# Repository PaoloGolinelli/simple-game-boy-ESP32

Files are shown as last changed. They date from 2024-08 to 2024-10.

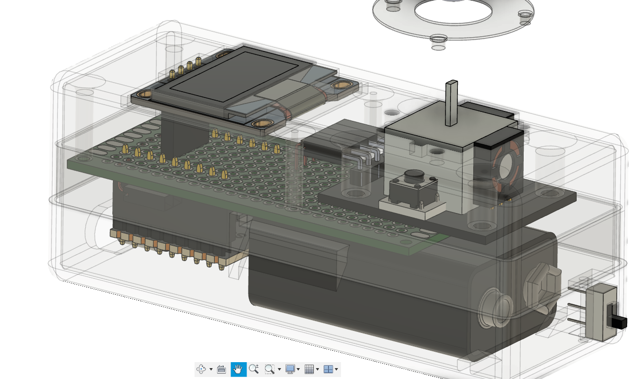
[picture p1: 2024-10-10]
circuit S3 mini/component_assembly_top_view.png

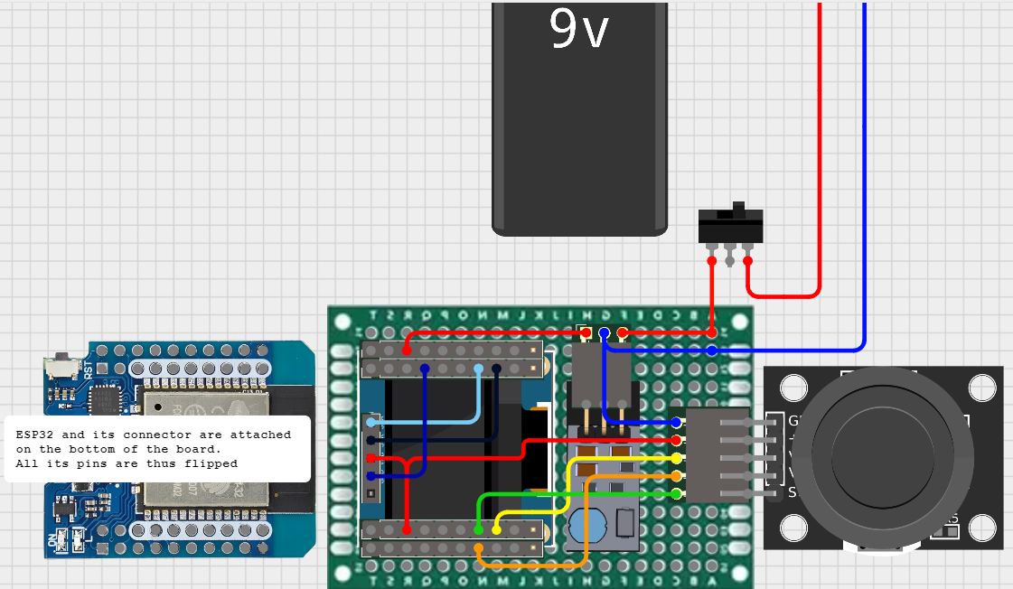
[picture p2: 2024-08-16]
circuit WROOM D1 mini/circuit_on_perfboard_schematic.png

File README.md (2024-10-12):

# simple-game-boy-ESP32
In this repository you can find all the material required to build a DIY console using the micro controller ESP32

## Content of the repository
- code for ESP32:
    In the beginning of the code you can select 3 preprocessor's variables which are used to differentiate between the boards you're using. 
    - MULTIPLAY: set to true to add the multiplayer games; require Bluethooth (BT) communication. Use this only if you plan on building two consoles to play with friends.
    - BT_CLASSIC: set to true if you want to use the classic BT protocol; set to false to use the BT Low Energy (BLE) protocol. If possible I recommend using the classic protocol, because it is faster and more resilient, but consumes more energy. ESP32 S3 mini has only BLE integrated, while WROOM has both.
    - ESP32_MOD: set to true if you're using WROOM module, false if youre using S3 mini. Used only to define the pins.

- schematic diagram of the circuit on breadboard
    Before building the whole console try it on breadboard to verify your board and components are compatible with the code.
    - S3 mini zero: https://app.cirkitdesigner.com/project/c8f486d2-5efd-4bba-b75a-e2c31b4107fe
    - WROOM D1 mini: https://app.cirkitdesigner.com/project/0857a7c8-4681-452b-a24f-5374fa44a8b1

- schematic diagram of the circuit to weld on matrix perforated board ("PCB")
    The 3D files to print the casing are specific to the S3 mini zero version. Even tho I provide the sketches to implement on perf-board with both micro-controllers, only the first is complete of all components.
    - S3 mini zero: https://app.cirkitdesigner.com/project/2bdec6b9-4f45-4acb-8dcb-3ecd578236df
        For the positioning of the components on the perfboard please refer to the 3D model of the assembly. Mind that some components are welded on the front, while others are on the back.
    - WROOM D1 mini: https://app.cirkitdesigner.com/project/fdfa9b3a-22b1-4d85-bbf5-8aa331098814

- stl file for 3D printing the case and positioning of the components
    - game_boy_assembly
    - top_cover
    - bottom_cover
    - joystick_head
    - joystick_lid
    - assembly_3Dprint_gcode_cura: CURA project with assembly, although you may configure it to your 3D printer settings

## Components required to make your own
- ESP32 S3 MINI Zero (or WROOM D1 mini)
- 2 axis joystick: KY-023
- LCD display: SSD1306 OLED 0.96'' I2C IIC 128x64
- breadboard
- jumper M/M
- jumper M/F
- matrix board 7x3
- slide switch: SS-12D00G 4mm
- 9V battery clip connector
- 9V battery
- step down voltage regulator: DD4012SA 5V

### Building Instructions 

## Required tools
- filament 3D printer
- welder

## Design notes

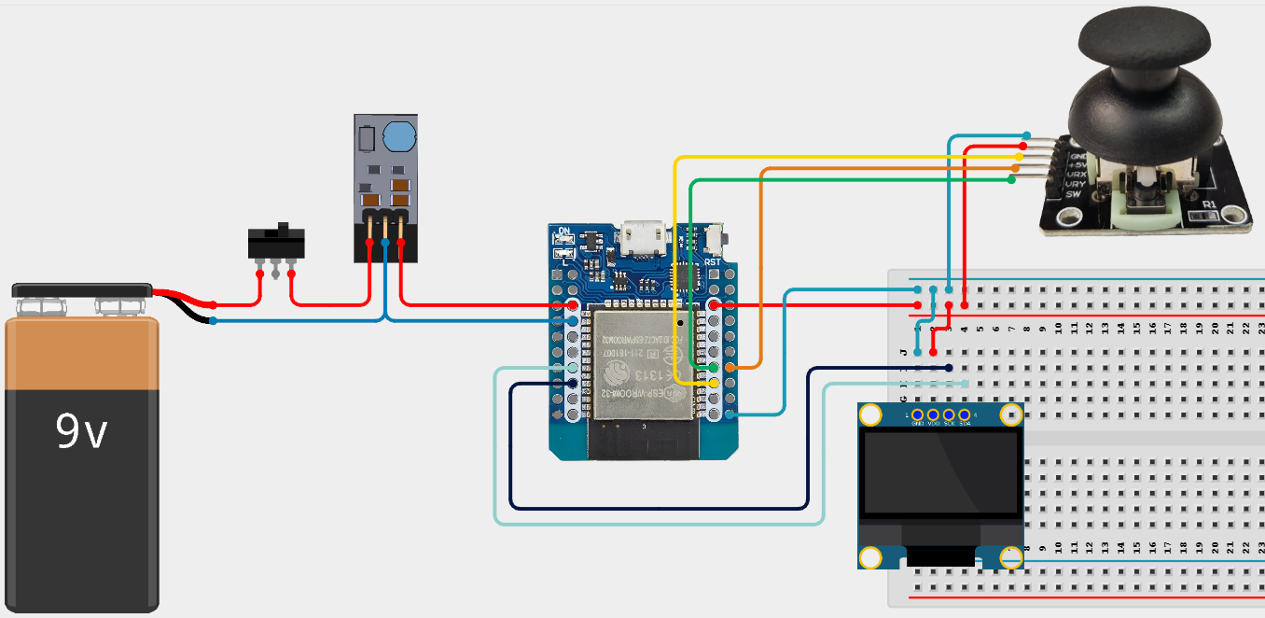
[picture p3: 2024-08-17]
circuit WROOM D1 mini/circuit_on_breadboard_schematic.png

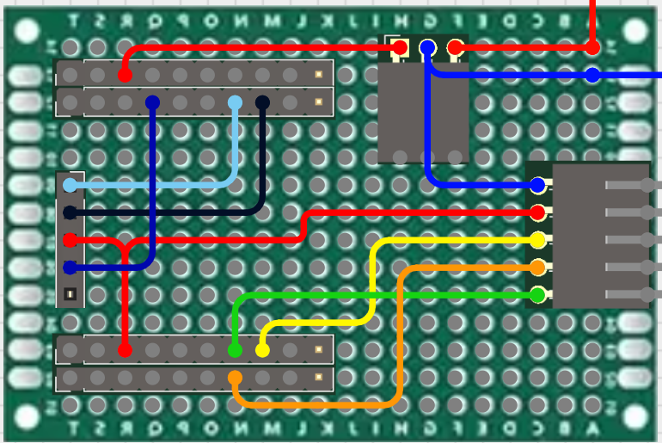
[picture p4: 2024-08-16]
circuit WROOM D1 mini/perfboard_circuit.png

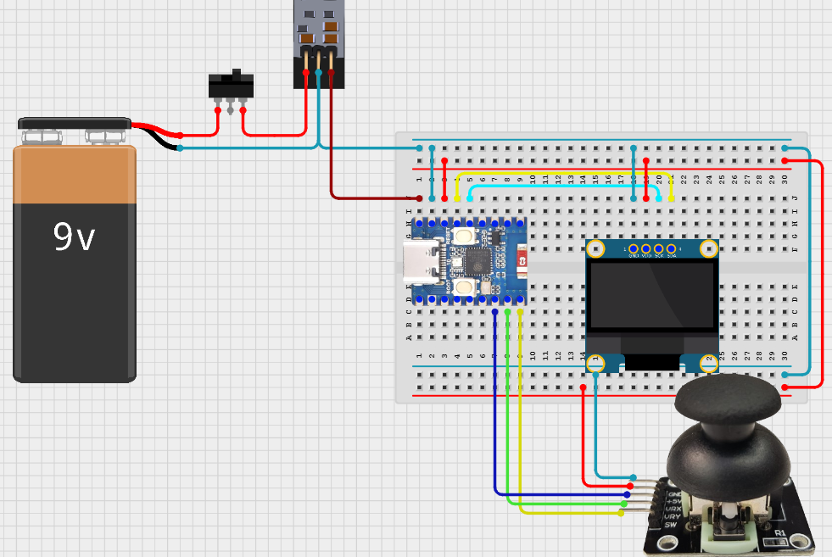
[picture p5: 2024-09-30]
circuit S3 mini/circuit_on_breadboard.png

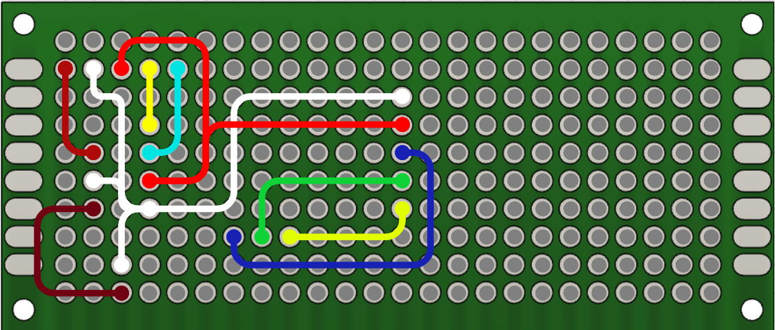
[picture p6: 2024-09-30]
circuit S3 mini/perfboard_circuit.png

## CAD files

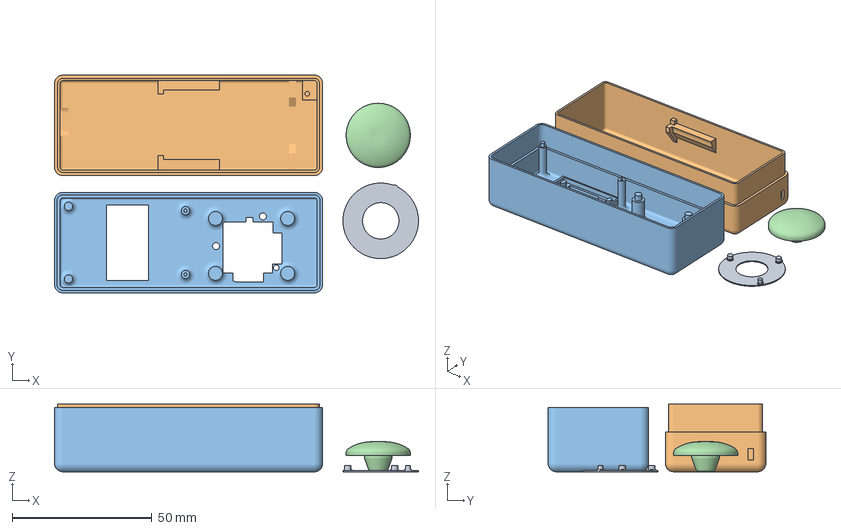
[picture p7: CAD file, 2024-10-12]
case 3D files/assembly_3Dprint_gcode_cura.3mf
130.3 x 78.0 x 24.2 mm
joystick_lid.stl
bottom_cover.stl
top_cover.stl
joy_head.stl

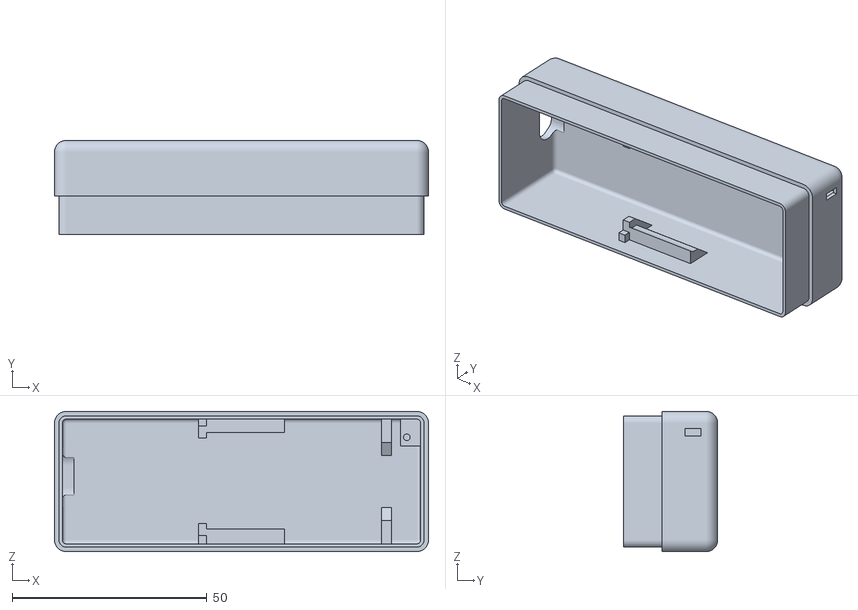
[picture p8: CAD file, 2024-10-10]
case 3D files/bottom_cover.stl
96.0 x 24.2 x 36.0

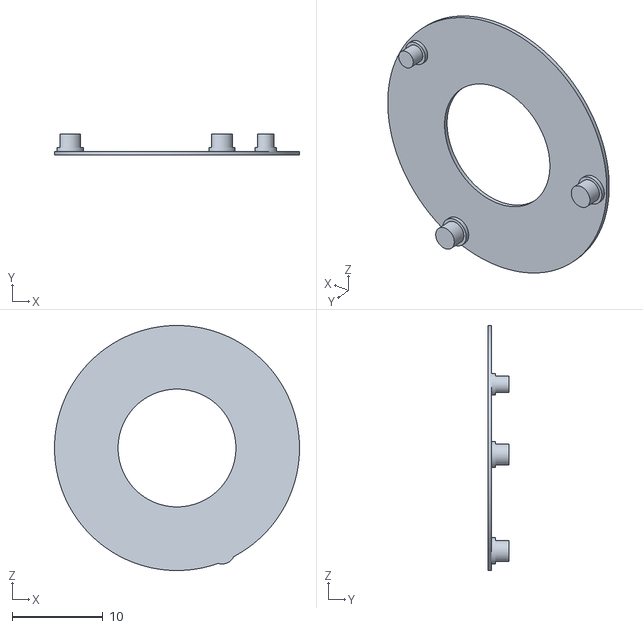
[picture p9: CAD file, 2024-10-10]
case 3D files/joystick_lid.stl
27.0 x 2.30 x 27.0

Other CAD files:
case 3D files/game_boy_assembly_fusion.f3z

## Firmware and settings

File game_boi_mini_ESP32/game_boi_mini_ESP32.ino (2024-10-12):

// -------------------------------------------------------------------------------------------------------
#define   MULTIPLAY       true    // set to true to allow for multiplayer games, otherwise set to false
#define   BT_CLASSIC      false   // set to true to use BT classic, false to use Bluetooth Low Energy 
#define   ESP32_MOD       false   // set to true if you want to use a ESP32 wroom, false to use a s3 mini 
// -------------------------------------------------------------------------------------------------------

#include <SPI.h>
#include <Wire.h>
#include <Adafruit_GFX.h>
#include <Adafruit_SSD1306.h>
#include <cmath>
#include <String.h>

#if (MULTIPLAY) // ------------------------- MULTIPLAYER
  #if (BT_CLASSIC)
    #include "BluetoothSerial.h"
    #include "esp_bt_device.h"
    #include <esp_mac.h>
  #else
    #include <BLEDevice.h>
    #include <BLEServer.h>
  #endif
#endif // ----------------------------------------------

// Macro functions
#define SIGN(x) ((x) > 0 ? 1 : ((x) < 0 ? -1 : 0))
#define ROUND_TO_1_DECIMALS(x) (int(x*10.0) / 10.0)


// Game parameters
#define   SCREEN_WIDTH    128   // OLED display width, in pixels
#define   SCREEN_HEIGHT   64    // OLED display height, in pixels
#define   SNAKE_WIDTH     6     // Snake display width, in pixels
#define   SNAKE_HEIGHT    6     // Snake display height, in pixels
#define   POOL_FORCE_COEF 5.6   // Multiplier of force to calc pool initial velocity 
const int t_menu =        700;  // if pressed for this amount of ms returns to menu
const int t_sample_menu = 200;  // ms each sample is made in the menu selection
const int t_bounce =      40;   // time in ms to account for switch bouncing
#define   ANALOG_RES      4095  // Resolution of ADC
#define   d_to_r          3.14/180.0


// Declaration for an SSD1306 display connected to I2C (default pins are SDA: GPIO21, SCL: GPIO22)
#define          OLED_RESET    -1    // Reset pin # (or -1 if sharing Arduino reset pin)
Adafruit_SSD1306 display (SCREEN_WIDTH, SCREEN_HEIGHT, &Wire, OLED_RESET);

// define a struct to handle coordinates (double x,y, and direction)
struct crd {  // coordinate
  double x;
  double y;
  int    d;   // snakes heading direction for each coordinate
};

#if (MULTIPLAY) // ------------------------- MULTIPLAYER
  #define NRGAMES 5   // number of games
  const char *options[NRGAMES] = { 
    " Snake ", 
    " Pool ", 
    " Hit the target ",
    " Pong multiplayer ",
    " Calibration "};
#else // --------------------------------- SINGLE PLAYER
  #define NRGAMES 4   // number of games
  const char *options[NRGAMES] = { 
    " Snake ", 
    " Pool ", 
    " Hit the target ",
    " Calibration "};
#endif // ----------------------------------------------

const char *difficult[3] = {
  " Easy ",
  " Medium ",
  " Hard " };

#if (ESP32_MOD) // Input Pin Wroom
  const int     AI1           = 35;   // IO26 - analog signal x joystick
  const int     AI2           = 26;   // IO18 - analog signal y joystick
  const int     switchPin     = 19;   // IO19
  const int     SCLpin        = 22;   // IO21
  const int     SDApin        = 21;   // IO21
#else           // Input Pin S3 mini
  const int     AI1           = 8;    // GP8 - analog signal x joystick
  const int     AI2           = 9;    // GP9 - analog signal y joystick
  const int     switchPin     = 7;    // GP7
  const int     SCLpin        = 2;    // GP1
  const int     SDApin        = 1;    // GP2
#endif

// global variables
int           gameRate;               // time in ms between moves
unsigned long t, t_press, t_release;

// snake variables
bool  alive           = true;       
int   length;                   // current snake length
crd   position[200]   = {0};    // array containing snake's position
crd   food;
int   nr_width        = SCREEN_WIDTH/SNAKE_WIDTH;
int   nr_height       = SCREEN_HEIGHT/SNAKE_HEIGHT;

// pool variables
crd          balls[4];          // initial position to be set at beginning of game
crd          b_vel[4];          // define the carthesian velocity of the balls
crd          stick[3];          // defines the position of the stick
bool         bhole[4];          // true if they end up in a hole
double       stick_angle, stick_F;
const double hole_R   = 7;
const double ball_R   = 4;
const double stick_L  = 18;
const double dt       = 0.03;   // integration time in seconds
const double fr_coeff = 0.4;    // friction coefficient

// hit the target variables
int           d_range = 8;
double        dist, dist_tot;
unsigned long t_tot;
double        score;

#if (MULTIPLAY) // ----------- MULTIPLAYER -------------------------
  // BlueTooth variable
  #if (BT_CLASSIC)
    BluetoothSerial SerialBT; 
    uint8_t slaveMACAddress[6] = {0x32, 0xAE, 0xA4, 0x07, 0x0D, 0x66}; // slave MAC address
    uint8_t oldMACAddress[6];
  #else
    #define SERVICE_UUID        "37859a32-9f35-4408-b4e8-ad61f9bc1f31"
    #define CHARACTERISTIC_UUID "e21f0560-f548-4c6c-a189-81b2264e5485"

    //static BLEUUID serviceUUID(SERVICE_UUID);
    //static BLEUUID charUUID(CHARACTERISTIC_UUID);
    static BLEUUID serviceUUID("37859a32-9f35-4408-b4e8-ad61f9bc1f31");     // DEBUG
    static BLEUUID charUUID("e21f0560-f548-4c6c-a189-81b2264e5485");

    // server
    BLEServer         *pServer          = NULL;
    BLECharacteristic *pCharacteristic  = NULL;
    bool    deviceConnected     = false;
    bool    oldDeviceConnected  = false;    
    // client
    static  BLERemoteCharacteristic *pRemoteCharacteristic;
    static  BLEAdvertisedDevice     *myDevice;
    static  boolean connected   = false;
    // common
    bool    notified;
    double  received_value;
  #endif

  // pong variables
  #define     XV        70      // ball's horizontal velocity
  #define     MAX_XV    110     // ball's max horizontal velocity
  double      max_t_v = 0.05;   // max pixels a tile can move per millisecond
  const int   tile_H  = 10;     // nr of pixels defining the tile height
  const int   tile_W  = 3;      // nr of pixels defining the tile width
  const int   bord_W  = 3;      // border width
  const int   v_bound = 10;     // pixel above field (for displaying score)
  const int   bR      = 2;      // ball radius
  crd         ball_xy;          // ball coordinates
  crd         ball_v;           // ball velocities
  double      t_y1, t_y2;       // y coordinates of the two tiles
  crd         pr_ball_xy;       // previous ball coordinates
  double      pr_y1, pr_y2;     // previous y coordinates of the two tiles
  double      Dt_y1;            // receiver tile difference with previous y coord
  bool        scored;           // turned to true when it needs to update the score
  bool        is_master;        // set to T when gaimboi is master in BT communication     
  bool        play_receive;     // set to T when the current device is receiving the ball
  int         score_1, score_2; // score of the two players

#endif // ----------------------------------------------------------


// joystick variables
double  xa = 238, xd = 4.30, xe = -10.89;  // parabola parameters
double  ya = 192, yd = 5.33, ye = -18.75;  // initial calibration
double  Xval, Yval, Xlin, Ylin, magn, theta;
int     dir, precDir;
bool    sw_press = true;

// menu variables
bool    gotomenu, mnpress, sw_rel;
int     selected = 0;
int     entered  = -1;

// Task handles for parallel programming
TaskHandle_t handle_snake_joy_read;

// functions
void starting_animation ();
void menu               ();                 // displays menu to choose the game
void readJoystick       ();                 // read joystick values
  void calculate_dir    ();                 // calculate direction indicated by joystick
  void calibrate        ();                 // calibration procedure defines parabola parameters to linearize joystick readings
void ICACHE_RAM_ATTR sw_activity (void);    // deals joystick switch pressing and releasing

void snake_game         (); 
  void move             (int);              // function moves snake accordingly to the direction
  void eat              (bool);             // if heading position equals food position it increment snakes length and place new food; bolean defines first call
  void printFrame       ();                 // print frame on display

void pool_game          ();
  void pool_aim         ();
  void pool_balls_anim  ();
  void pool_printfield  (bool = false, bool = false);
  void collision        (int, int);
  void hole_ball        (int);

void target_game        ();

#if (MULTIPLAY) // -------------- MULTIPLAYER GAMES ----------
void pong_game          ();
  bool initialize_BT    ();                 // starts BT in master/slave mode and pair the devices
#if (!BT_CLASSIC)
  bool connectToServer  ();                 // used by slave to connect to server
#endif
  void pong_printfield  ();                 // prints the two tiles, the ball and the score 
#endif // ----------------------------------------------------


void setup() {
  Serial.begin(115200);
  Serial.printf("\nInitiate adjustment\n");

  pinMode(switchPin, INPUT_PULLUP);

  Wire.begin(SDApin, SCLpin); // define the pins for I2C (SDA, SCL)

  attachInterrupt(digitalPinToInterrupt(switchPin), sw_activity, CHANGE);
  t_release = millis();
  t_press   = millis();

  // SSD1306_SWITCHCAPVCC = generate display voltage from 3.3V internally
  if(!display.begin(SSD1306_SWITCHCAPVCC, 0x3C)) { // Address 0x3D for 128x64
    Serial.println(F("SSD1306 allocation failed"));
    for(;;) delay(1); // Don't proceed, loop forever
  }

  // starting animation "GAIM BOY"
  starting_animation();

  delay(500);
  display.clearDisplay();

  display.setTextColor(1); display.setTextSize(1);
  display.setCursor(5, 20); display.print("At any moment press");
  display.setCursor(5, 29); display.print("the switch for ~1 s");
  display.setCursor(5, 38); display.print(" to return to menu");
  display.display();

  delay(100);

  // display "press button":
  while (sw_press)
    delay(1);

  // Milliseconds at which switch is pressed defines random seed
  randomSeed(millis()%1000);

  // menù here going through the games
  menu();
}


void loop() {

  if (gotomenu) {
    menu();
  }
  if (selected == 0) 
    snake_game();
  else if (selected == 1) {
    pool_game();
  }
  else if (selected == 2) {
    target_game();
  }
#if (MULTIPLAY) // ----------- MULTIPLAYER ---------
  else if (selected == 3) {
    pong_game();
  }
  else if (selected == 4) {
    calibrate();
  }
#else // -------------------- SINGLE PLAYER --------
  else if (selected == 3) {
    calibrate();
  }
#endif // ------------------------------------------

  delay(100);
}


void starting_animation() {
  double  tsnake = 120;
  double  angle;
  int     sign;
  crd     aimer;
  aimer.x = 160;
  aimer.y = 40;

  display.setTextColor(1);
  display.setTextSize(3);

  // balls initial position and velocities
  balls[0].x = 23;    balls[0].y = 41;
  b_vel[0].x = 0;     b_vel[0].y = 0;
  balls[1].x = -6;    balls[1].y = 36;
  b_vel[1].x = 35.5;  b_vel[1].y = 10;

  t_tot = millis();
  while (millis() - t_tot <= 3000) {
    display.clearDisplay();
    display.setCursor(28, 0);   display.println(F("GAIM"));
    display.setCursor(37, 43);  display.println(F("B I"));

    // calculate new aimer coords
    aimer.x = 64.0 + 2.0*pow(3.0-((millis()-t_tot)/1000.0), 2);
    aimer.y = 54.0 - 2.2*pow(3.0-((millis()-t_tot)/1000.0), 3);

    display.drawCircle(aimer.x, aimer.y, d_range, 1);
    display.drawCircle(aimer.x, aimer.y, 2, 1);
    display.drawFastHLine(aimer.x-(d_range+1), aimer.y, 2*(d_range+1)+1, 1);
    display.drawFastVLine(aimer.x, aimer.y-(d_range+1), 2*(d_range+1)+1, 1);

    for (int i = 0; i < 2; i++) {
      balls[i].x += b_vel[i].x * dt;
      balls[i].y += b_vel[i].y * dt;

      // dinamic rolling friction:
      angle = atan(b_vel[i].y/b_vel[i].x);
      sign = b_vel[i].x >= 0 ? 1 : -1;
  
      if (fabs(b_vel[i].x) > 0.11)
        b_vel[i].x -= sign*0.2*cos(angle);
      else
        b_vel[i].x = 0;   // static friction: too slow -> come to a stop

      if (fabs(b_vel[i].y) > 0.11)
        b_vel[i].y -= sign*0.2*sin(angle);
      else
        b_vel[i].y = 0;   // static friction 

      display.fillCircle(balls[i].x, balls[i].y, ball_R, 1);
    }

    if (sqrt(pow(balls[0].x - balls[1].x, 2) + pow(balls[0].y - balls[1].y, 2)) <= 2*ball_R)
      collision(0, 1);

    display.display();
  }

  int sn_d = 16; // snake dimension
  display.setTextColor(0);
  display.setTextSize(2);

  // snake's initial positions
  length = 6;
  for (int s = length-1; s >=0 ; s--) {
    position[s].x = -sn_d*s - sn_d/2; 
    position[s].y = SCREEN_HEIGHT/2+2;
  }

  for (int n = 0; n < 2*(length)+3; n++) {
    t = millis();
    display.display();

    for (int l = 0; l < length; l++)
      position[l].x += sn_d/2;

    display.fillRect(0, SCREEN_HEIGHT/2-10, SCREEN_WIDTH, 20, 0);

    // display snake's head
    display.fillRoundRect(position[0].x-sn_d/2-5, position[0].y-sn_d/2, sn_d+5, sn_d, sn_d/4+1, 1); // below mouth

    if (n < 2*length-4 || n >= 2*length-1)
      display.fillTriangle(position[0].x-3, position[0].y, position[0].x+sn_d/2, position[0].y+1, position[0].x+sn_d/2, position[0].y-1, 0); // mouth
    else
      display.fillTriangle(position[0].x-1, position[0].y, position[0].x+sn_d/2, position[0].y+5, position[0].x+sn_d/2, position[0].y-5, 0); // mouth

    for (int l = 1; l < length-1; l++)
      display.fillRect(position[l].x - sn_d/2, position[l].y - sn_d/2, sn_d, sn_d, 1);

    display.fillCircle(position[0].x-8, position[0].y-8, 4, 1);                                 // above eye
    display.fillCircle(position[0].x-8, position[0].y-8, 2, 0);                                 // eye

    // display tail
    display.fillRect(position[length-1].x-sn_d, position[length-1].y-sn_d/2, sn_d+8, sn_d, 1);

    display.fillCircle(position[length-1].x+3, position[length-1].y+sn_d/2+1, 7, 0);
    display.fillCircle(position[length-1].x-6, position[length-1].y-sn_d/2-1, 7, 0);
    display.fillTriangle(position[length-1].x-sn_d, position[length-1].y-sn_d/2, position[length-1].x-sn_d, position[length-1].y+sn_d/2, position[length-1].x-sn_d+9, position[length-1].y+sn_d/2, 0);

    display.fillCircle(balls[0].x, balls[0].y, ball_R, 1);  // display deleted ball
    display.fillCircle(balls[1].x, balls[1].y, ball_R, 1);  // display deleted ball

    display.setCursor(-65+n*sn_d/2, SCREEN_HEIGHT/2-5); display.print(F("MINI"));

    while (millis() - t < tsnake)
      delay(1);
  }
}


void menu () {
  gotomenu = false;
  selected = 0;
  
  while(!sw_press)
    delay(1);

  mnpress = false;
  while (true) {
    readJoystick();
    calculate_dir();

    if (dir == 1) {
      selected--;
    }
    else if (dir == 3) {
      selected++;
    }

    selected = (selected + NRGAMES) % NRGAMES;

    if (mnpress) {
      break;
    }
    else {
      display.clearDisplay();
      display.setTextSize(1);             
      display.setTextColor(SSD1306_WHITE);
      display.setCursor(0,0);
      display.println(F("Games"));
      display.println("");

      for(int i=0; i < NRGAMES; i++) {
        if (i == selected) {
          display.setTextColor(SSD1306_BLACK, SSD1306_WHITE);
          display.println(options[i]);
        }
        else if (i != selected) {
          display.setTextColor(SSD1306_WHITE);
          display.println(options[i]);
        }
      }
      display.display();
      delay(t_sample_menu);
    }
  }
}

/*---------------------
  |       SNAKE       |
  --------------------- */
// function called on secondary core to run in parallel with snake main loop
// it reads the joistick inputs so that the other core can  
void snake_joy_read(void *parameter) {  
  while (true) {
    vTaskDelay(1);  // Short delay to yield control
  
    // Read the joystick and calculate the direction
    readJoystick();

    calculate_dir();

    if (!alive) {
      break;
    }
  }

  vTaskDelete(NULL);
}

void snake_game() {
  while(!sw_press)
    delay(1);
  
  selected  = 0;
  mnpress   = false;
  while (true) {
    readJoystick();
    calculate_dir();

    if (dir == 1) {
      selected--;
    }
    else if (dir == 3) {
      selected++;
    }

    selected = (selected + 3) % 3;

    if (mnpress) {
      break;
    }
    else {
      display.clearDisplay();
      display.setTextSize(1);             
      display.setTextColor(SSD1306_WHITE);
      display.setCursor(0,0);
      display.println(F("Select difficulty"));
      display.println("");

      for(int i=0; i < 3; i++) {
        if (i == selected) {
          display.setTextColor(SSD1306_BLACK, SSD1306_WHITE);
          display.println(difficult[i]);
        }
        else if (i != selected) {
          display.setTextColor(SSD1306_WHITE);
          display.println(difficult[i]);
        }
      }
      display.display();
      delay(t_sample_menu);
    }
  }

  // select difficulty
  if (selected == 0) 
    gameRate = 420;
  else if (selected == 1)
    gameRate = 320;
  else
    gameRate = 220;

  // defines initial position
  position[0].x = nr_width/2 + 1;
  position[0].y = nr_height/2;
  position[0].d = 2;
  position[1].x = nr_width/2;
  position[1].y = nr_height/2;
  position[1].d = 2;
  position[2].x = nr_width/2 - 1;
  position[2].y = nr_height/2;
  position[2].d = 2;
  length  = 2;  // incremented to 3 by eat(true) call
  precDir = 2;
  eat(true);    // defines first food position
  alive = true;

  // call to handle_snake_joy_read task on secondary core
  xTaskCreatePinnedToCore(
    snake_joy_read,           // Function to implement the task
    "snake_joy_read",         // Name of the task
    2048,                     // Stack size in words
    NULL,                     // Task input parameter
    1,                        // Priority of the task
    &handle_snake_joy_read,   // Task handle
    0);                       // Core where the task should run


  while (alive) {
    t = millis();
  
    if (dir == 0)
      dir = precDir;

    // controls new direction isn't the opposite of of current heading
    if ((dir+2)%4 == precDir%4) {
      dir = precDir;
    }

    move(dir);
    precDir = dir;
    
    printFrame();
    
    eat(false);  // false because it's not the first call
        
    while (millis() - t < gameRate)
      delay(1);
  }

  display.clearDisplay();
  display.setTextSize(2);     
  display.setTextColor(SSD1306_WHITE);
  display.setCursor(SCREEN_WIDTH/2-50, SCREEN_HEIGHT/2-20);
  display.println("GAME OVER");
  display.println("");
  display.setCursor(SCREEN_WIDTH/2-52, SCREEN_HEIGHT/2+2);
  display.print("Score: ");
  display.println(length-3);
  display.display();

  gotomenu = true;

  while(sw_press)
    delay(1);
}

void move(int drct) {
/*  Dir | heading
     1  | up
     2  | right
     3  | dowm
     4  | left    */

  int newX = position[0].x;
  int newY = position[0].y;

  if (drct == 1) {
    if (position[0].y == 0)
      alive = false;

    newY--;
  }
  else if (drct == 2) {
    if (position[0].x == nr_width-1)
      alive = false;

    newX++;
  }
  else if (drct == 3) {
    if (position[0].y == nr_height-1)
      alive = false;

    newY++;
  }
  else if (drct == 4) {
    if (position[0].x == 0)
      alive = false;

    newX--;
  }

  // moves the coordinates down the snake one at a time
  for (int t = length-1; t >= 0; t--) {
    position[t+1].x = position[t].x;
    position[t+1].y = position[t].y;
    position[t+1].d = position[t].d;
  }

  // verify the head doesn't collide with snake
  for (int k = 0; k < length; k++) {
    if (newX == position[k].x && newY == position[k].y) {
      alive = false;
    }
  }

  // assign new heading position
  position[0].x = newX;
  position[0].y = newY;
  position[0].d = drct;
}

void eat(bool first) {
  if (first || (position[0].x == food.x && position[0].y == food.y)) {
    length++;

    bool notPresent = false;
    while (!notPresent) {
      notPresent = true;

      food.x = random(nr_width);
      food.y = random(nr_height);

      for (int l = 0; l < length; l++) {
        if (food.x == position[l].x && food.y == position[l].y) {
          notPresent = false;
          break;
        }
      }
    }
  }
}

void printFrame() {
  int imin, imax, jmin, jmax;

  display.clearDisplay();
  
  display.drawFastHLine(0, 0, SCREEN_WIDTH, 1);
  display.drawFastHLine(0, SCREEN_HEIGHT-1, SCREEN_WIDTH, 1);
  display.drawFastVLine(0, 0, SCREEN_HEIGHT, 1);
  display.drawFastVLine(SCREEN_WIDTH-1, 0, SCREEN_HEIGHT, 1);

  for (int s = 0; s < length; s++) {

    if (position[s].d == 2 || position[s-1].d == 4)
      imin = 0;
    else
      imin = 1;

    if (position[s].d == 4 || position[s-1].d == 2)
      imax = SNAKE_WIDTH;
    else
      imax = SNAKE_WIDTH-1;

    if (position[s].d == 3 || position[s-1].d == 1)
      jmin = 0;
    else
      jmin = 1;

    if (position[s].d == 1 || position[s-1].d == 3)
      jmax = SNAKE_HEIGHT;
    else
      jmax = SNAKE_HEIGHT-1;
    
    display.fillRect(position[s].x*SNAKE_WIDTH + imin, position[s].y*SNAKE_HEIGHT + jmin + 1, imax - imin, jmax - jmin, 1);
  }

  if (position[0].d == 2 || position[0].d == 4) {
    display.fillCircle(position[0].x*SNAKE_WIDTH + SNAKE_WIDTH/2, position[0].y*SNAKE_HEIGHT+1 + 1, 1, 1);
    display.fillCircle(position[0].x*SNAKE_WIDTH + SNAKE_WIDTH/2, (position[0].y+1)*SNAKE_HEIGHT-1 + 1, 1, 1);
  }
  else if (position[0].d == 1 || position[0].d == 3) {
    display.fillCircle(position[0].x*SNAKE_WIDTH+1, position[0].y*SNAKE_HEIGHT + SNAKE_HEIGHT/2 + 1, 1, 1);
    display.fillCircle((position[0].x+1)*SNAKE_WIDTH-1, position[0].y*SNAKE_HEIGHT + SNAKE_HEIGHT/2 + 1, 1, 1);
  }

  display.fillCircle(food.x*SNAKE_WIDTH + SNAKE_WIDTH/2, food.y*SNAKE_HEIGHT + SNAKE_HEIGHT/2 + 1, SNAKE_WIDTH/2, 1);

  display.display();
}
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

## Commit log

2024-08-16 added breadboard schematic
2024-08-16 added schematics for breadboard and perfboard
2024-09-30 implemented code and circuits on ESP32 S3 mini
2024-10-10 added joystick head file
    [bottom_cover.stl, game_boy_assembly_fusion.f3z, joystick_lid.stl]
2024-10-12 added gcode for 3D printing
    [assembly_3Dprint_gcode_cura.3mf]
